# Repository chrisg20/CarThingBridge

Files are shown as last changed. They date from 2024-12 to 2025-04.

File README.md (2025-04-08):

# CarThingBridge
A compact connector board for the Spotify Car Thing and Raspberry Pi Zero, for use with [Nocturne](https://github.com/usenocturne/nocturne-image).

3D printed mount on Printables [here](https://www.printables.com/model/1098732-car-thing-pi-bridge).

Screenshot 2024-12-04 at 3 33 04 PM
Screenshot 2024-12-04 at 3 33 04 PM

# Ordering Instructions
I no longer sell the boards due to lower demand, high tariffs, etc. 

If you want one, it is worth asking on the Nocturne Discord server to see if other users have extra boards that they would be willing to give or sell to you. 

Server: https://discord.gg/GTP9AawHPt

To order boards yourself, follow these steps:

**Order PCB Only (Manual Assembly)**

Manual assembly should only be attempted if you are experienced in soldering very small (0603) components.

* Download the ZIP archive: https://github.com/chrisg20/CarThingBridge/PCB/production/.
* Visit https://JLCPCB.com and click Order Now.
* Upload Bridge_v1.zip from the PCB/production/ directory.
* VERY IMPORTANT! Set PCB Layers to 2 and Thickness to 0.8mm — this is required for the straddle-mounted USB-C connector.
* Order components from Digi-Key, Mouser, etc.
* Required Components (per PCB):
  * CX60-24S-UNIT (x1)
  * CX90M-16P (x1)
  * SSSS811101 (x1)
  * ZX60-B-5S(31) (x2)
  * 0603WAF5101T5E (x3)

**Order PCB with Assembly**

* Enable PCB Assembly during order setup.
* On the Bill of Materials page:
* Upload bom.csv from PCB/production/.
* Upload positions.csv from PCB/production/.
* Review the component placement preview to ensure it looks correct.

You will receive the a notification to pay an additional ~$50 for a fixture required for the USB-C connector (C5338340).

# Instructions

Print the mount and install 4 M2.5x3mm inserts into the holes. Place adhesive strips into the slots and attach to the car thing so that the Nocturne logo bar lines up with the left edge of the Car Thing as shown in the image below.

Screenshot 2024-12-04 at 3 33 04 PM

Connect the Raspberry Pi to the bridge and the bridge to the Car Thing. Secure the Raspberry Pi to the mount with 4 M2.5x4mm screws. Ensure the small switch is set to ON (away from the Raspberry Pi) as shown.

Screenshot 2024-12-04 at 3 33 04 PM

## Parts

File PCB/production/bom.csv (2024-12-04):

Designator | Footprint | Quantity | Value | LCSC Part #
J1, J2 | CONN_ZX60-B-5S31_HIR | 2 | USB_B_Micro
J3 | HIROSE_CX60-24S-UNIT | 1 | CX60-24S-UNIT
J4 | CX90M-16P_HIR | 1 | CX90M-16P
R1, R2, R3 | 0603 | 3 | 5K1
S1 | SW_SSSS811101 | 1 | SSSS811101

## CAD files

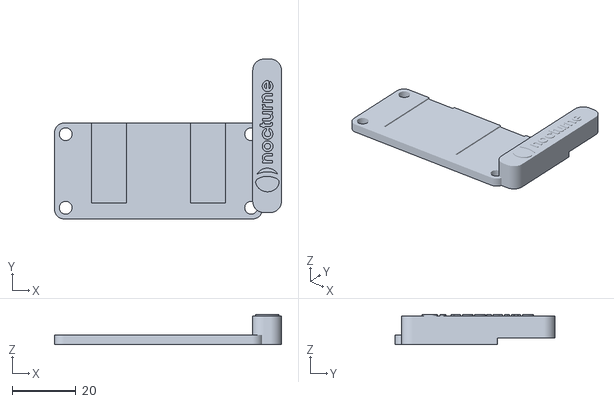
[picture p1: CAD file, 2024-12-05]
3D Model/3D Printed Mount.stl
71.0 x 50.0 x 9.40

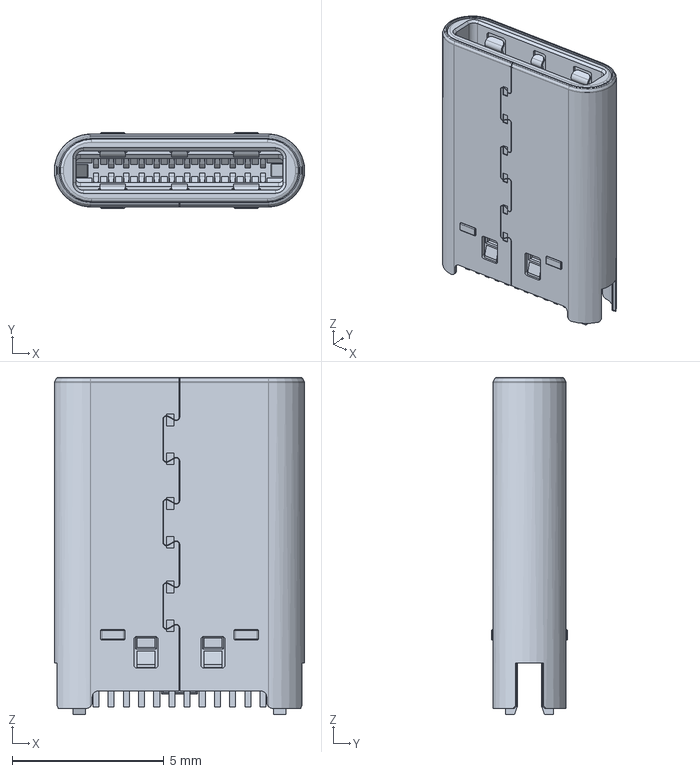
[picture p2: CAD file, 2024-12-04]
PCB/3D Models/CX60-24S-UNIT.step
8.25 x 2.52 x 11.1 mm

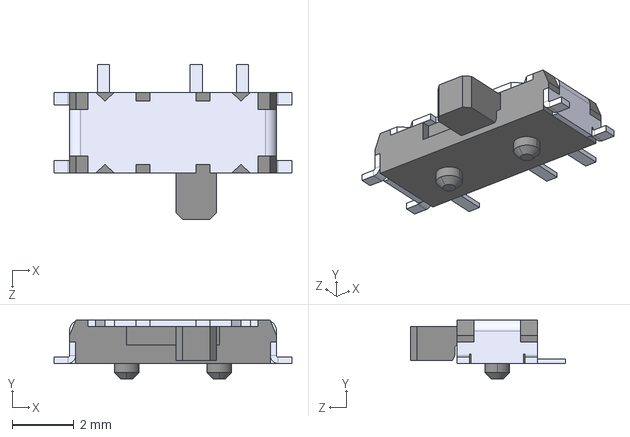
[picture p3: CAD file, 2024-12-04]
PCB/3D Models/SSSS811101.step
7.70 x 1.90 x 5.00 mm

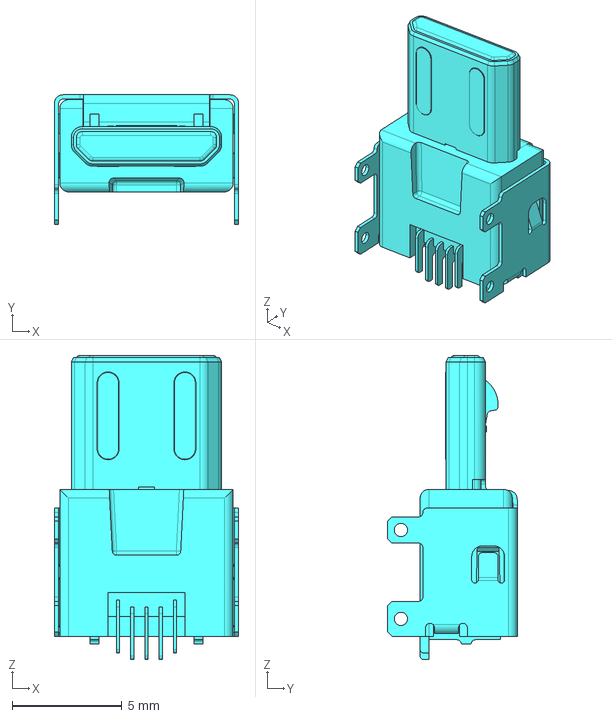
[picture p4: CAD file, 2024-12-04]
PCB/3D Models/ZX60-B-5S.stp
8.40 x 5.90 x 13.8 mm

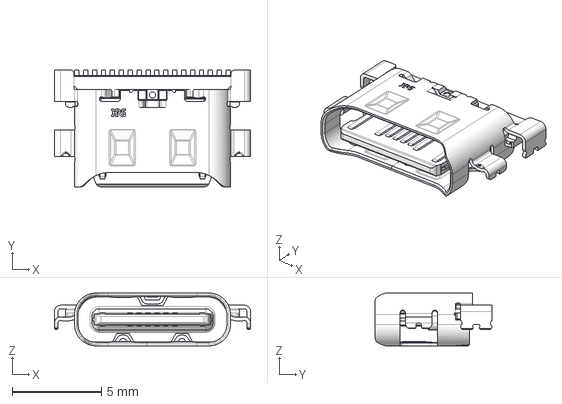
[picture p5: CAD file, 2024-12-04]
PCB/3D Models/CX90M-16P_4800513000_3D_STEP.stp
11.0 x 6.55 x 2.97 mm

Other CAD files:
3D Model/3D Printed Mount.f3d

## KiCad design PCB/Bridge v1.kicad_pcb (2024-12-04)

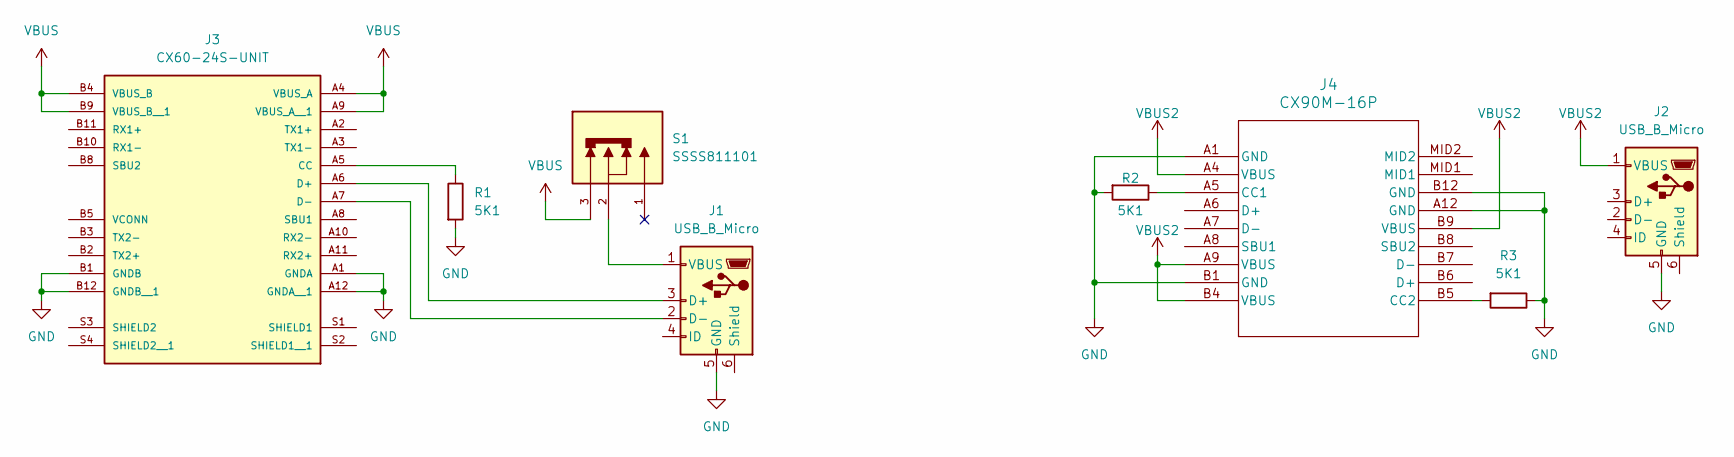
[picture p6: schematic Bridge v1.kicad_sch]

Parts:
J1, J2: USB_B_Micro; CONN_ZX60-B-5S31_HIR
J3: CX60-24S-UNIT; HIROSE_CX60-24S-UNIT; PARTREV 5
J4: CX90M-16P; CX90M-16P_HIR
R1, R2, R3: 5K1; R_0603_1608Metric
S1: SSSS811101; SW_SSSS811101; PARTREV N/A

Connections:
GND: J1.5 (GND), J2.5 (GND), J3.A1 (GNDA), J3.A12 (GNDA__1), J3.B1 (GNDB), J3.B12 (GNDB__1), J4.A1 (GND), J4.A12 (GND), J4.B1 (GND), J4.B12 (GND), R1.2, R2.2, R3.1
unnamed: J1.3 (D+), J3.A6 (D+)
unnamed: J1.2 (D-), J3.A7 (D-)
unnamed: J1.1 (VBUS), S1.2
unnamed: J3.A5 (CC), R1.1
unnamed: J4.A5 (CC1), R2.1
unnamed: J4.B5 (CC2), R3.2
VBUS: J3.A4 (VBUS_A), J3.A9 (VBUS_A__1), J3.B4 (VBUS_B), J3.B9 (VBUS_B__1), S1.3
VBUS2: J2.1 (VBUS), J4.A4 (VBUS), J4.A9 (VBUS), J4.B4 (VBUS), J4.B9 (VBUS)

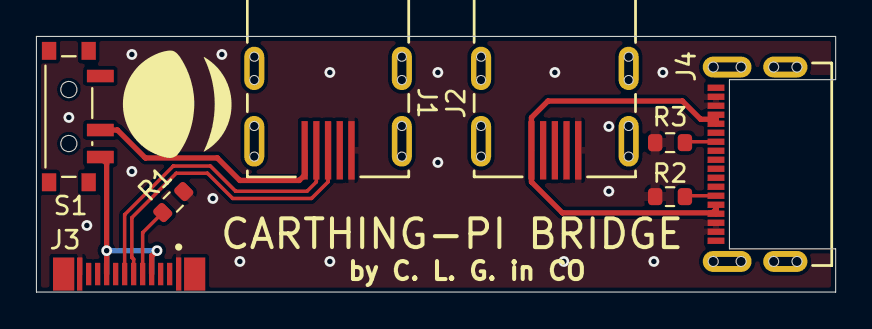
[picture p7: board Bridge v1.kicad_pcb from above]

Board: 2 copper layers, 44.4 x 14.2 mm, 8 parts (0 on the bottom side), 9 nets.

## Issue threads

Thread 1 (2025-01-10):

USB-C Female 90 degree from board posible?

Dinico414, 2025-01-10:
Would it be possible for you to make a second version of the pcb where the plug for the usb cable is 90 degree instead of flat on the pcb? Would be very usefull for my usecase. Dont know how easy it would be to change that and order that. And maybe let me know how to give questions and requests. Because i know thats not the way but i dont know how else thanks.

Closed 2025-01-10.

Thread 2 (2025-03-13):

Component List

dreyes15, 2025-03-13:
Is there anyway to get a list of needed components and where to purchase them for building our own Pi Bridge?

chrisg20, 2025-03-15:
Component list is located at PCB/production/bom.csv :)

Closed 2025-03-15.
